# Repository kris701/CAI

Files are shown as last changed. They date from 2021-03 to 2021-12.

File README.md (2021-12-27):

banner
# Centralised Auxiliary Interface (CAI)

A project about centralizing a lot of the auxiliary systems for my 3D printer.
As well as add some new systems, like auto-screws, that makes the operation of the printer a lot easier!
It is also designed to be mounted on my [toolhead extension project](https://github.com/kris701/SnapMaker-Toolhead-Extensions).

### Auto-Screws
Automatic screws to take heatbed and toolhead off and on, to make it significantly easier to switch between CNC, Laser engraver and 3D-printer!

<p align="center">
  
  
</p>

### Menu System
Easy to modify menu system, with a rotary push button control.

menuWorks

### Auto-Setup
Single menu item, to setup all thats needed for CNC or 3D print.
Consisting of tightening screws, turning on LED and for 3D printing, turn on the nozzle blower.

autosetup

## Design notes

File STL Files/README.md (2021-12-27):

## Print Parts
### Interface Board
| InterfaceBoardModule_case | InterfaceBoardModule_Lid | InterfaceBoardModule_Knob |
|:---:|:---:|:---:|
| *Case* | *Lid* | *Knob* |

### LED Holder
| LEDHolder |
|:---:|
| *LED Holder* |

### Motor Controller Module
| MotorControllerModule_Case | MotorControllerModule_Lid |
|:---:|:---:|
| *Case* | *Lid* |

### Motherboard Module
| MotherboardModule_Case | MotherboardModule_Lid | MotherboardModule_Cover |
|:---:|:---:|:---:|
| *Case* | *Lid* | *Cover (Optional)* |

Note: The Cover should be printed in rubber filament.

### Screw Module
| ScrewModuleMk1_MainBody | ScrewModuleMk1_Lid |
|:---:|:---:|
| *Case* | *Lid* |

Note: These parts should be printed with very high infil, and in PETG if possible, since they will be exposed to a lot of heat and force.

### Backplate Extension
| SnapmakerBackplateExtension_Case | SnapmakerBackplateExtension_Lid | SnapmakerBackplateExtension_SideCap | SnapmakerBackplateExtension_TopCap |
|:---:|:---:|:---:|:---:|
| *Case* | *Lid* | *Side Cap (Optional)* | *Top Cap (Optional)* |

Note: The caps should be printed in rubber filament.

### Transistor Module Mk. 1
| TransistorModuleMk1_Case | TransistorModuleMk1_Lid |
|:---:|:---:|
| *Case* | *Lid* |

### Transistor Module Mk. 2
| TransistorModuleMk2_Case | TransistorModuleMk2_Lid |
|:---:|:---:|
| *Case* | *Lid* |

### Wire Holder (Optional)
| WireHolder |
|:---:|
| *Wire Holder (Optional)* |

The parts are put together with some M3 screws and bolts that i had. As well as being mounted to the printer with M4 screws.

## Printer settings

The config for a SnapMaker Original can be found under "Printing Config"

General config:

|Setting|Value|
|:---:|:---:|
| Layer Height |0.2mm |
| Top Thickness |0.8mm |
| Infil |35% |

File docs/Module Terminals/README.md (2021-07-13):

# Module Terminal Configuration
This is a little documentation on how i set up all the terminals on my setup.
It should however be noted, that you can set up the terminals however you want.

## Motherboard Module


The remaining ones for this module, is the interface board connector (7-pin) and the power connector (right next to it)

## Motor Controller Module
motorcontroller_b
motorcontroller_a

## Transistor Module
The transistor modules simply consist of a Type A input, and a Type D output.

## Screw Modules
Consist of just a Type D port.

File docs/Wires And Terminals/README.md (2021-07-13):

# Wires
Almost all cables in the project, consist of either 2 or 3 inner wires. (With the exception of the 7-pin cable for the front panel)
All the wires are made on a 1-1 basis, where each pin is connected to the same pin in the other end:



This makes it so that the same wires can be used for almost all ports (except if its a type D wire)

# Terminals
Pretty much all plugs is GX16-3-pin aviation plugs.
There are some different setups, for different terminals. But in general, they are intented to share some commonality.

All in all there are 3 different 3-proned terminals from the main controller:
## Type A
Type A is the basic variant, consisting of power and a single signal wire.

plugTypeA

## Type B
Type B is for motor controllers, where two are needed. One that has the GND plug, and one that has the +12v plug.

PlugTypeB

## Type C
Type C is for special future expansion, where the RX/TX pins can be used.

PlugTypeC

## Type D
There are also some wires and terminals, that only use two terminals (usually from a module to the thing being controlled, e.g. from a Transistor Module to LEDs)
They are esentially no different than the Base terminal, except there are no Signal:

PlugTypeD

(Note, that i removed the third pron from the connectors for all Type D terminals, so not to cause confusion)

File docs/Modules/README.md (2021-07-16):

# Overview of all modules

squareoverall

# Interface Module Mk. 1


# Transistor Module Mk. 1


# Transistor Module Mk. 2


# Back Extension Plates


# Motherboard Module Mk. 2


# Motor Controller Module Mk. 1


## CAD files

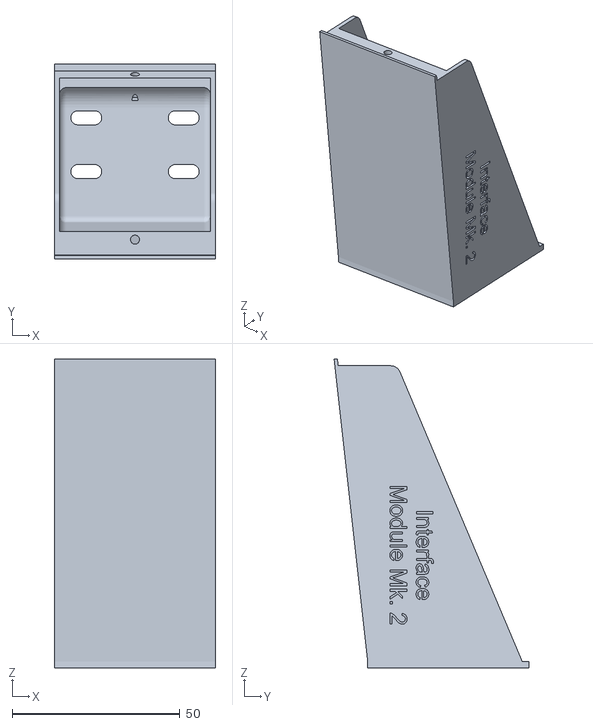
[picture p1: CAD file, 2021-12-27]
STL Files/Interfaceboard-Module-Case/InterfaceBoardModule_Case.stl
48.0 x 58.0 x 92.0

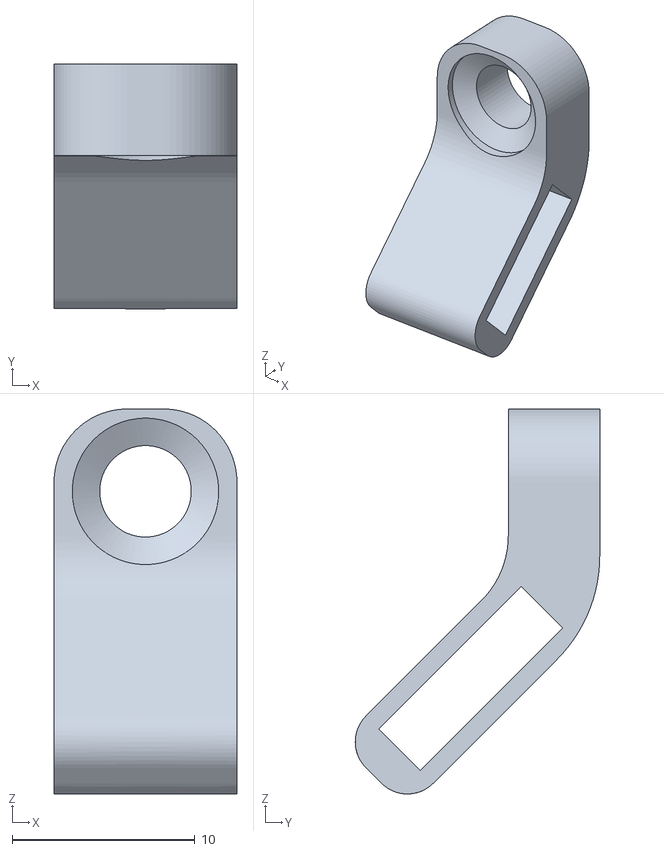
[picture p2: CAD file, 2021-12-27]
STL Files/LED-Holder/LEDHolder.stl
10.0 x 13.4 x 21.0

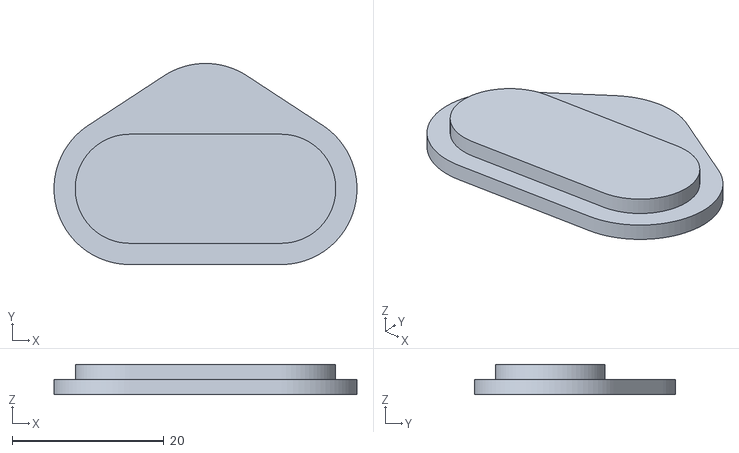
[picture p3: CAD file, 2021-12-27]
STL Files/Motherboard-Module-Case/MotherboardModule_Cover.stl
40.0 x 26.5 x 4.00

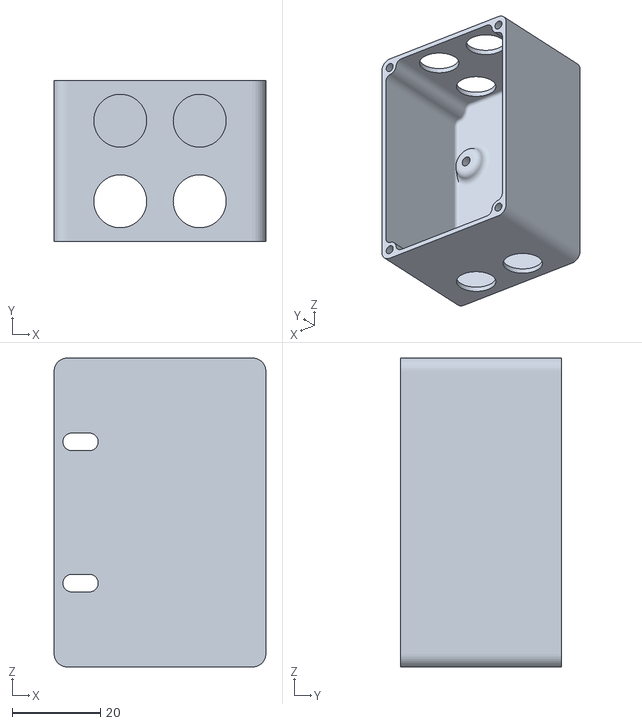
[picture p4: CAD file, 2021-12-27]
STL Files/Motor-Controller-Module-Case/MoterControllerModule_Case.stl
48.0 x 36.5 x 70.0

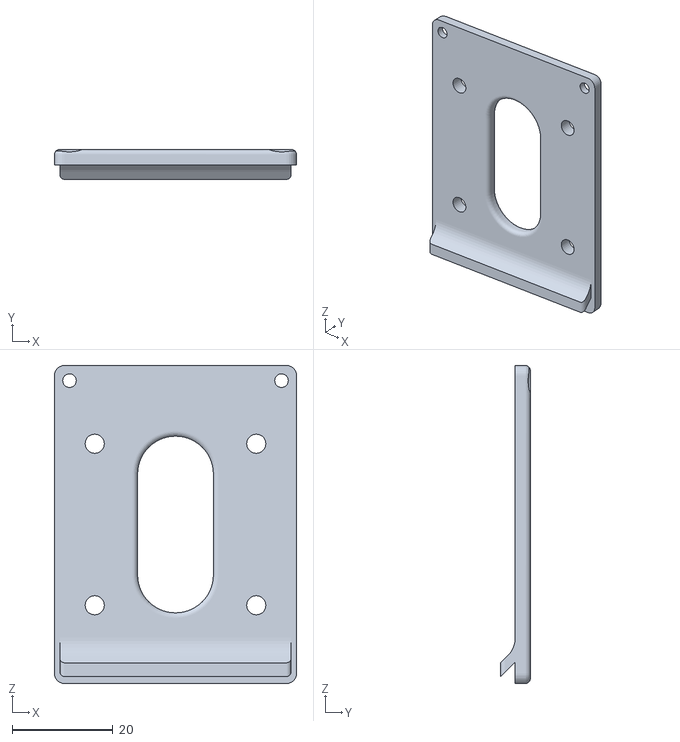
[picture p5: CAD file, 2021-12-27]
STL Files/Snapmaker-Backplate-Extension/SnapmakerBackplateExtension_Lid.stl
48.0 x 5.90 x 63.0

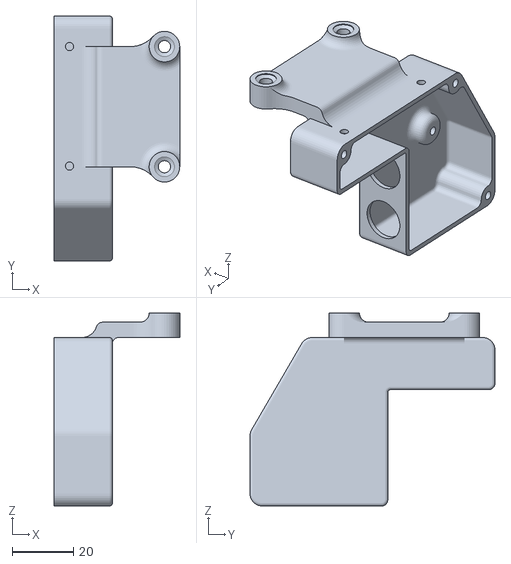
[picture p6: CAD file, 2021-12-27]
STL Files/Transistor-Module-Mk2/TransistorModuleMk2_Case.stl
41.0 x 80.0 x 63.0

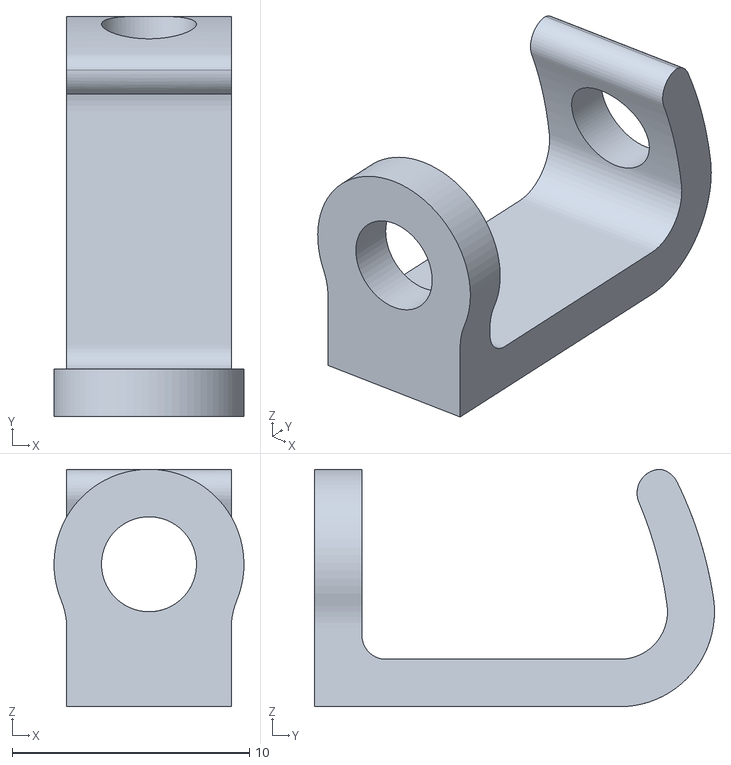
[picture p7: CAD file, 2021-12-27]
STL Files/Wire-Holder/WireHolder.stl
8.00 x 16.8 x 10.0

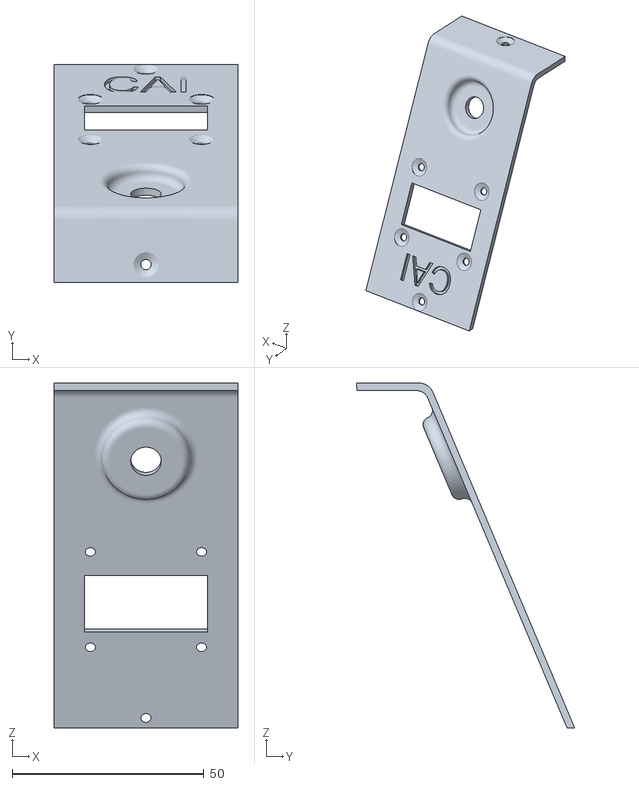
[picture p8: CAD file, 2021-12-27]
STL Files/Interfaceboard-Module-Case/InterfaceBoardModule_Lid.stl
48.0 x 57.0 x 90.0

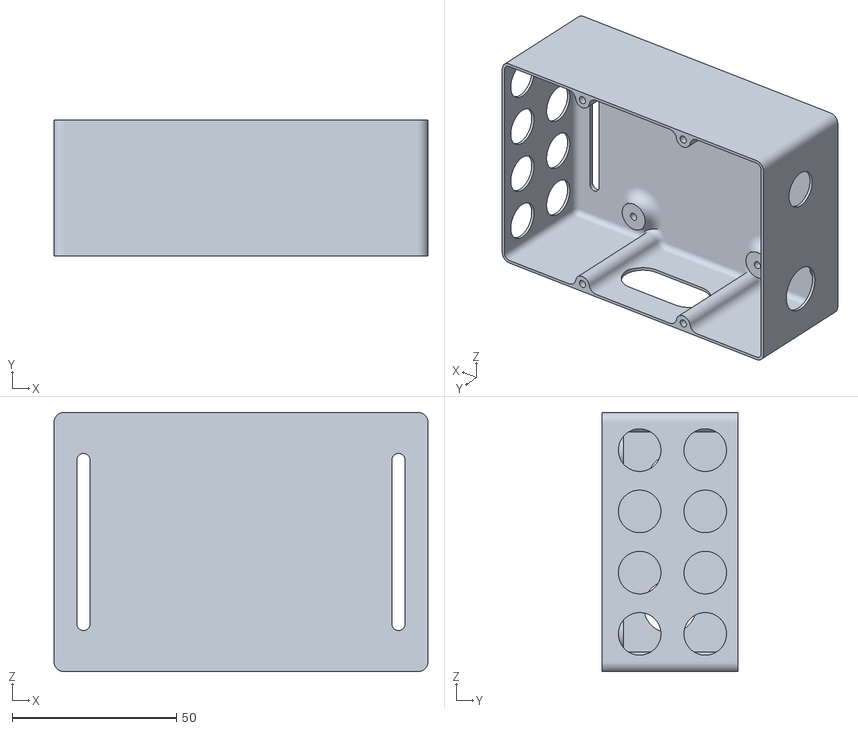
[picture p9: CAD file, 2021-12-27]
STL Files/Motherboard-Module-Case/MotherboardModule_Case.stl
114.0 x 41.5 x 79.0

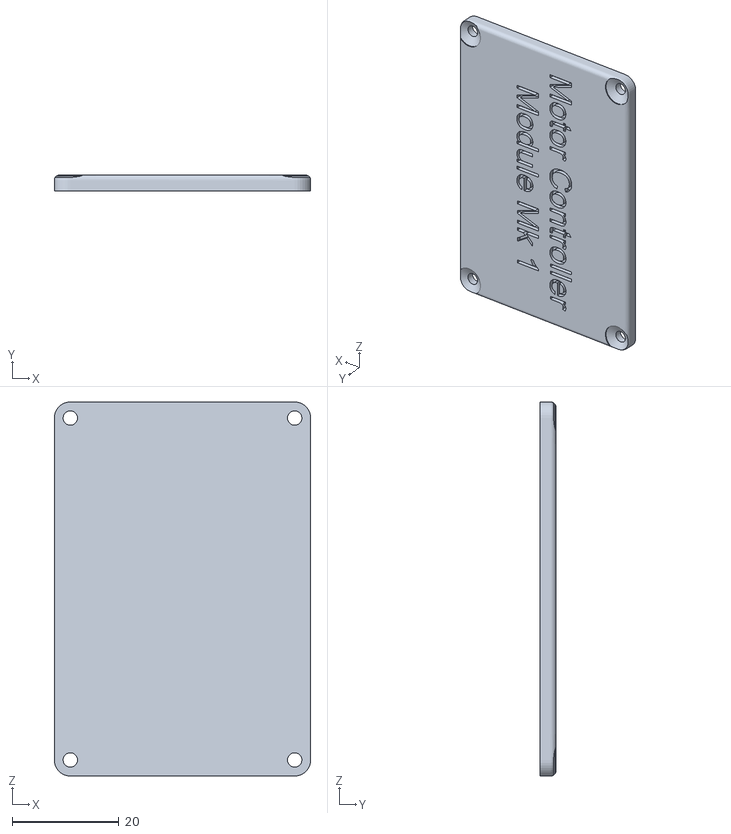
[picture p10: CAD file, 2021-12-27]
STL Files/Motor-Controller-Module-Case/MoterControllerModule_Lid.stl
48.0 x 3.00 x 70.0

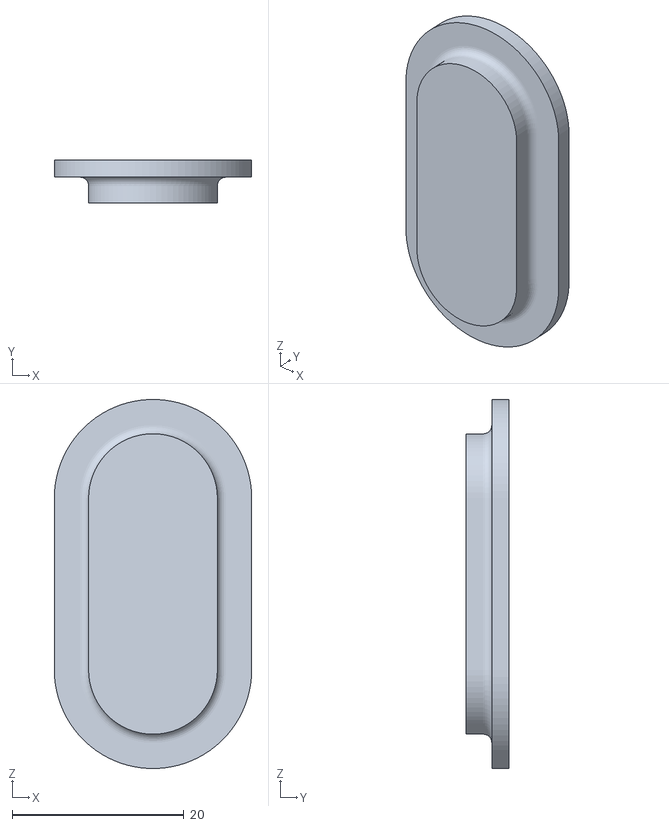
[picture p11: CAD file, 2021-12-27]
STL Files/Snapmaker-Backplate-Extension/SnapmakerBackplateExtension_TopCap.stl
23.0 x 5.00 x 43.0

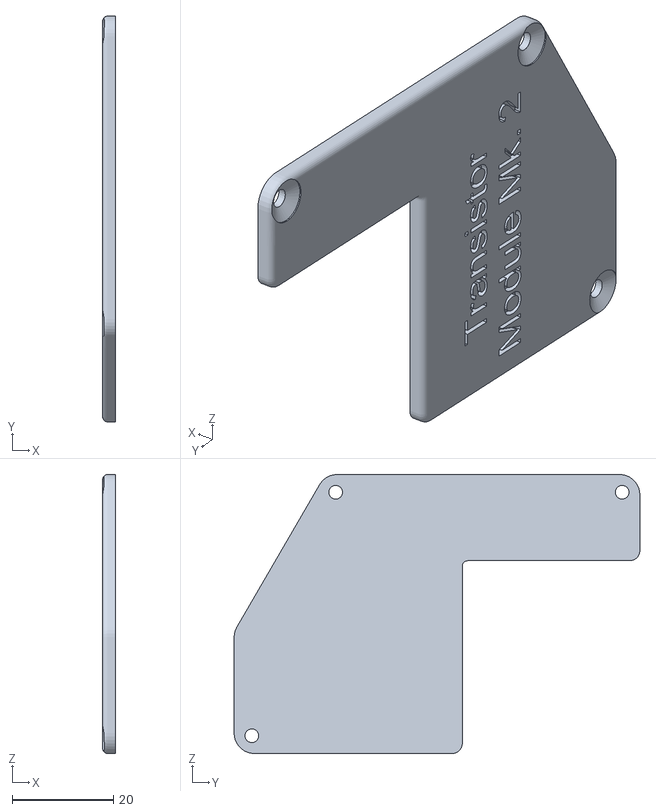
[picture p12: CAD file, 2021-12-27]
STL Files/Transistor-Module-Mk2/TransistorModuleMk2_Lid.stl
2.50 x 80.0 x 55.0

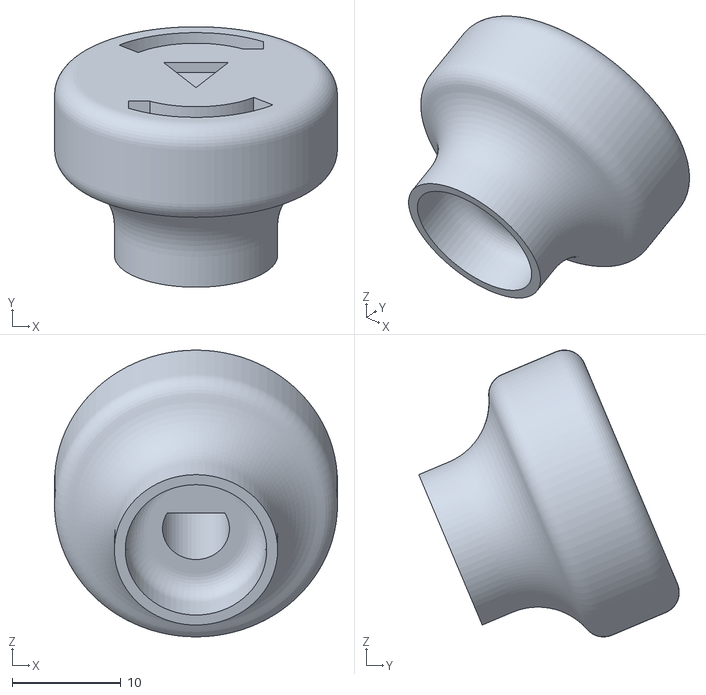
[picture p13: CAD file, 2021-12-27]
STL Files/Interfaceboard-Module-Case/InterfaceBoardModule_Knob.stl
26.0 x 23.9 x 26.3

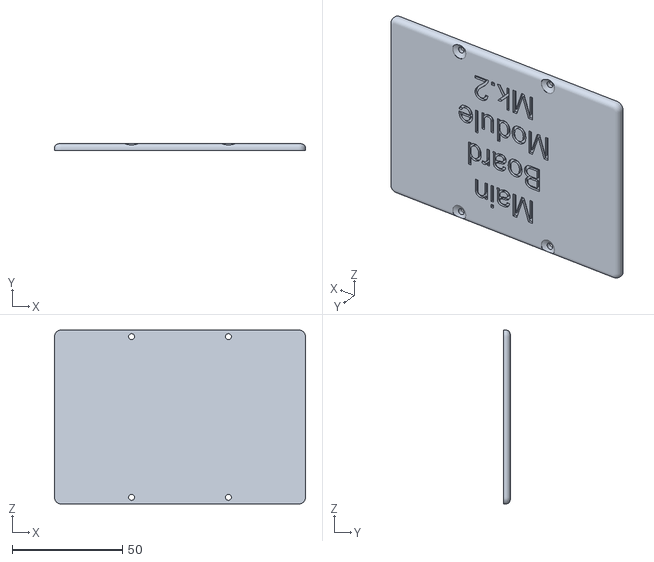
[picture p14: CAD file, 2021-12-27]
STL Files/Motherboard-Module-Case/MotherboardModule_Lid.stl
114.0 x 3.00 x 79.0

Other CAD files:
STL Files/Snapmaker-Backplate-Extension/SnapmakerBackplateExtension_Case.stl
STL Files/Snapmaker-Backplate-Extension/SnapmakerBackplateExtension_SideCap.stl
STL Files/Screw-Module-Mk1/ScrewModuleMk1_MainBody.stl
STL Files/Screw-Module-Mk1/ScrewModuleMk1_Lid.stl
3D Models/Interfaceboard-Module-Case/InterfaceBoardCaseMk2 v29.f3d
3D Models/LED-Holder/LED_Holder_Back v4.f3d
3D Models/Motherboard-Module-Case/MainBoardModuleCaseMk2 v26.f3d
3D Models/Motor-Controller-Module-Case/MotorControllerCase v6.f3d
3D Models/Screw-Module-Mk1/ScrewModule.f3d
3D Models/Snapmaker-Backplate-Extension/backextensionplate-Mk2 v25.f3d
3D Models/Transistor-Module-Mk1/TransisorModuleCase v19.f3d
3D Models/Transistor-Module-Mk2/TransisorModuleCaseMk2.f3d
3D Models/Wire-Holder/WireHolder v3.f3d
STL Files/Transistor-Module-Mk1/TransistorModuleMk1_Case.stl
STL Files/Transistor-Module-Mk1/TransistorModuleMk1_Lid.stl

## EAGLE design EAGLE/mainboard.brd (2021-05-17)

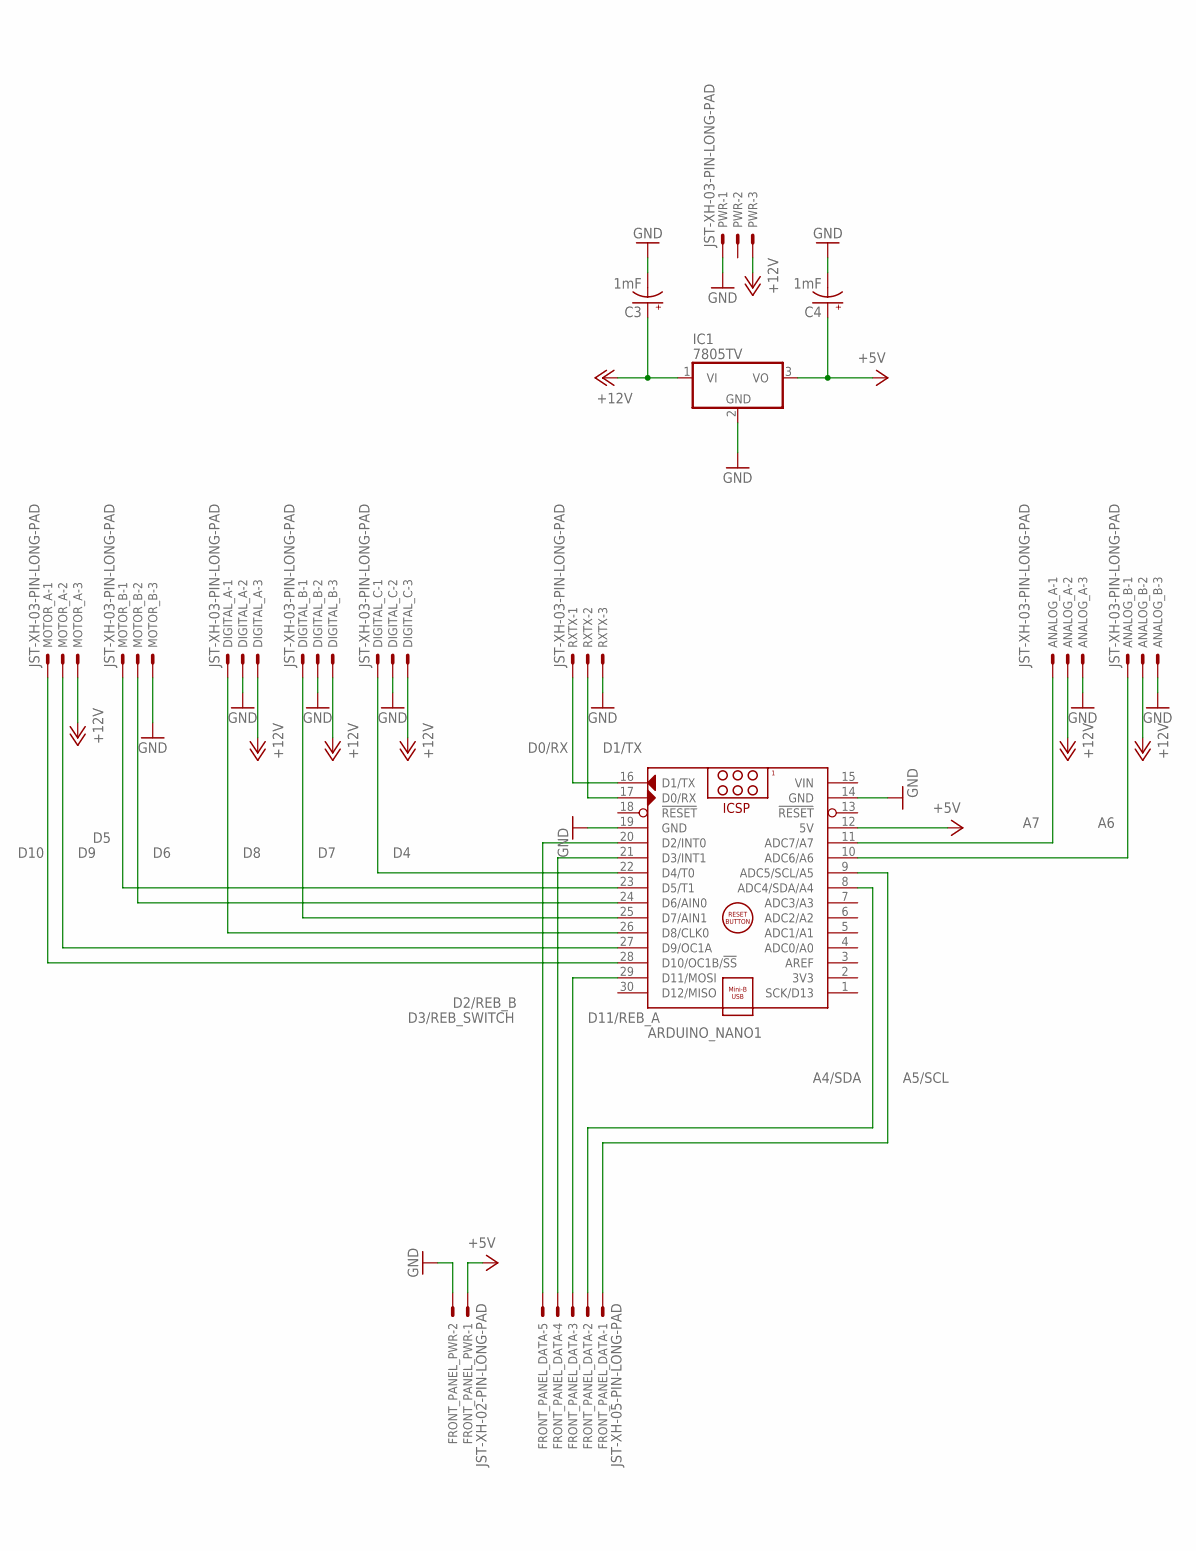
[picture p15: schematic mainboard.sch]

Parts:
ANALOG_A: JST-XH-03-PIN-LONG-PAD; JST-XH-03-PACKAGE-LONG-PAD
ANALOG_B: JST-XH-03-PIN-LONG-PAD; JST-XH-03-PACKAGE-LONG-PAD
ARDUINO_NANO1: ARDUINO_NANO
C3, C4: 1mF; CPOL-RADIAL-5MM-10MM
DIGITAL_A: JST-XH-03-PIN-LONG-PAD; JST-XH-03-PACKAGE-LONG-PAD
DIGITAL_B: JST-XH-03-PIN-LONG-PAD; JST-XH-03-PACKAGE-LONG-PAD
DIGITAL_C: JST-XH-03-PIN-LONG-PAD; JST-XH-03-PACKAGE-LONG-PAD
FRONT_PANEL_DATA: JST-XH-05-PIN-LONG-PAD; JST-XH-05-PACKAGE-LONG-PAD
FRONT_PANEL_PWR: JST-XH-02-PIN-LONG-PAD; JST-XH-02-PACKAGE-LONG-PAD
IC1: 7805TV; TO220V
MOTOR_A: JST-XH-03-PIN-LONG-PAD; JST-XH-03-PACKAGE-LONG-PAD
MOTOR_B: JST-XH-03-PIN-LONG-PAD; JST-XH-03-PACKAGE-LONG-PAD
PWR: JST-XH-03-PIN-LONG-PAD; JST-XH-03-PACKAGE-LONG-PAD
RXTX: JST-XH-03-PIN-LONG-PAD; JST-XH-03-PACKAGE-LONG-PAD

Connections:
+5V: ARDUINO_NANO1.12 (5V), C4.+, FRONT_PANEL_PWR.1, IC1.3 (VO)
+12V: ANALOG_A.2, ANALOG_B.2, C3.+, DIGITAL_A.3, DIGITAL_B.3, DIGITAL_C.3, IC1.1 (VI), MOTOR_A.3, PWR.3
A4/SDA: ARDUINO_NANO1.8 (ADC4/SDA/A4), FRONT_PANEL_DATA.2
A5/SCL: ARDUINO_NANO1.9 (ADC5/SCL/A5), FRONT_PANEL_DATA.1
A6: ANALOG_B.1, ARDUINO_NANO1.10 (ADC6/A6)
A7: ANALOG_A.1, ARDUINO_NANO1.11 (ADC7/A7)
D0/RX: ARDUINO_NANO1.17 (D0/RX), RXTX.2
D1/TX: ARDUINO_NANO1.16 (D1/TX), RXTX.1
D2/REB_B: ARDUINO_NANO1.20 (D2/INT0), FRONT_PANEL_DATA.5
D3/REB_SWITCH: ARDUINO_NANO1.21 (D3/INT1), FRONT_PANEL_DATA.4
D4: ARDUINO_NANO1.22 (D4/T0), DIGITAL_C.1
D5: ARDUINO_NANO1.23 (D5/T1), MOTOR_B.1
D6: ARDUINO_NANO1.24 (D6/AIN0), MOTOR_B.2
D7: ARDUINO_NANO1.25 (D7/AIN1), DIGITAL_B.1
D8: ARDUINO_NANO1.26 (D8/CLK0), DIGITAL_A.1
D9: ARDUINO_NANO1.27 (D9/OC1A), MOTOR_A.2
D10: ARDUINO_NANO1.28 (D10/OC1B/!SS), MOTOR_A.1
D11/REB_A: ARDUINO_NANO1.29 (D11/MOSI), FRONT_PANEL_DATA.3
GND: ANALOG_A.3, ANALOG_B.3, ARDUINO_NANO1.14 (GND), ARDUINO_NANO1.19 (GND), C3.-, C4.-, DIGITAL_A.2, DIGITAL_B.2, DIGITAL_C.2, FRONT_PANEL_PWR.2, IC1.2 (GND), MOTOR_B.3, PWR.1, RXTX.3
VIN: ARDUINO_NANO1.15 (VIN)

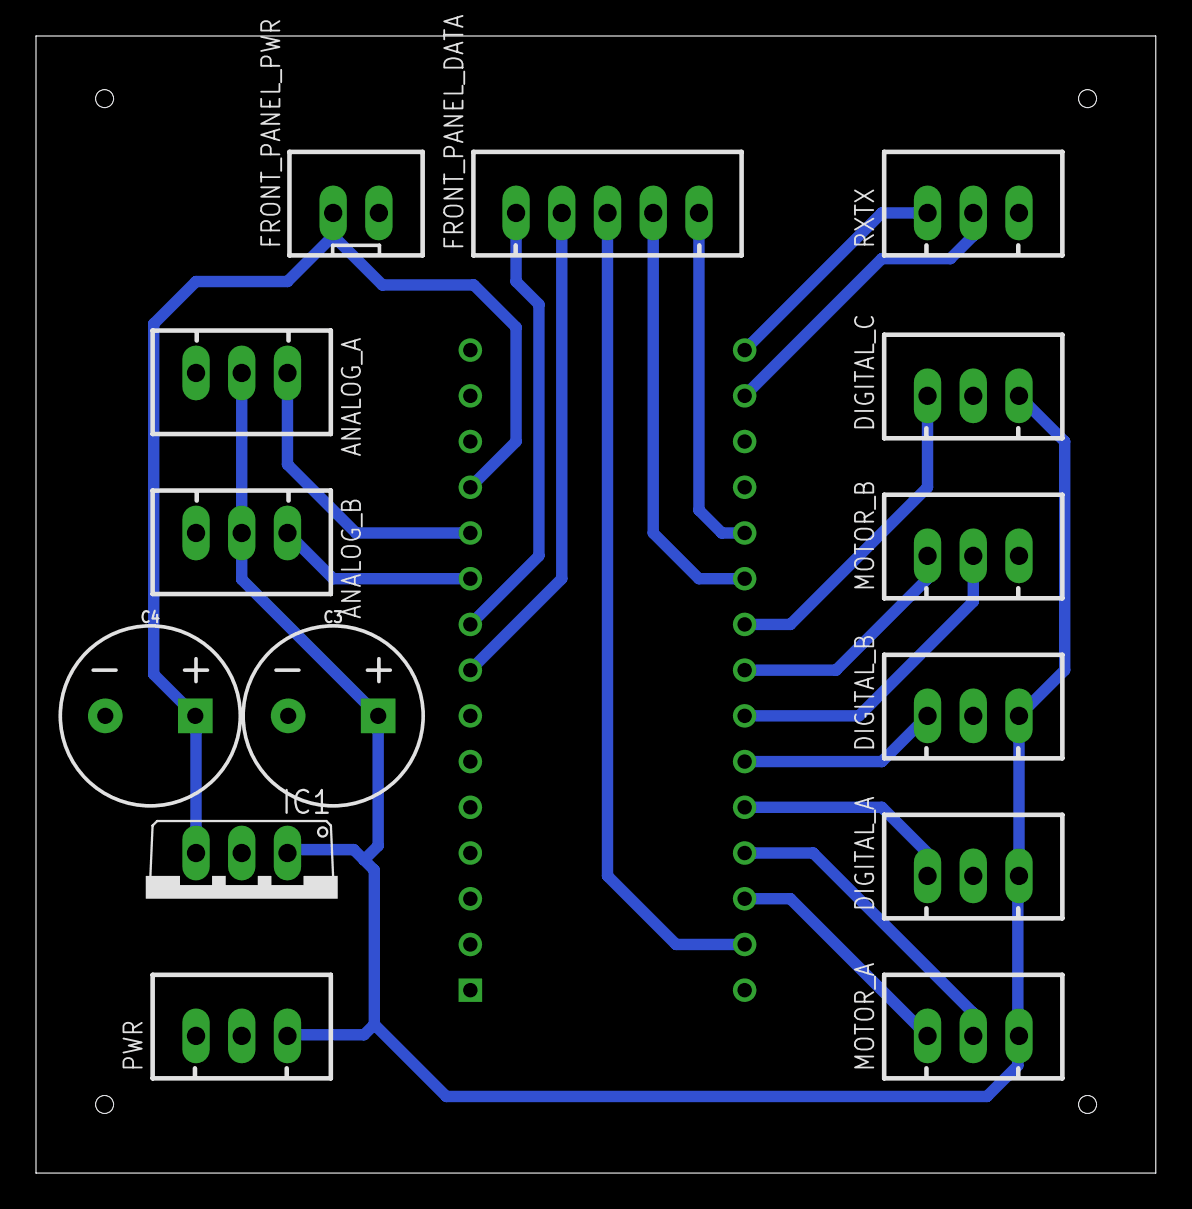
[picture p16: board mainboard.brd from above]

Board: 2 copper layers, 62.2 x 63.2 mm, 15 parts (1 on the bottom side), 19 nets.

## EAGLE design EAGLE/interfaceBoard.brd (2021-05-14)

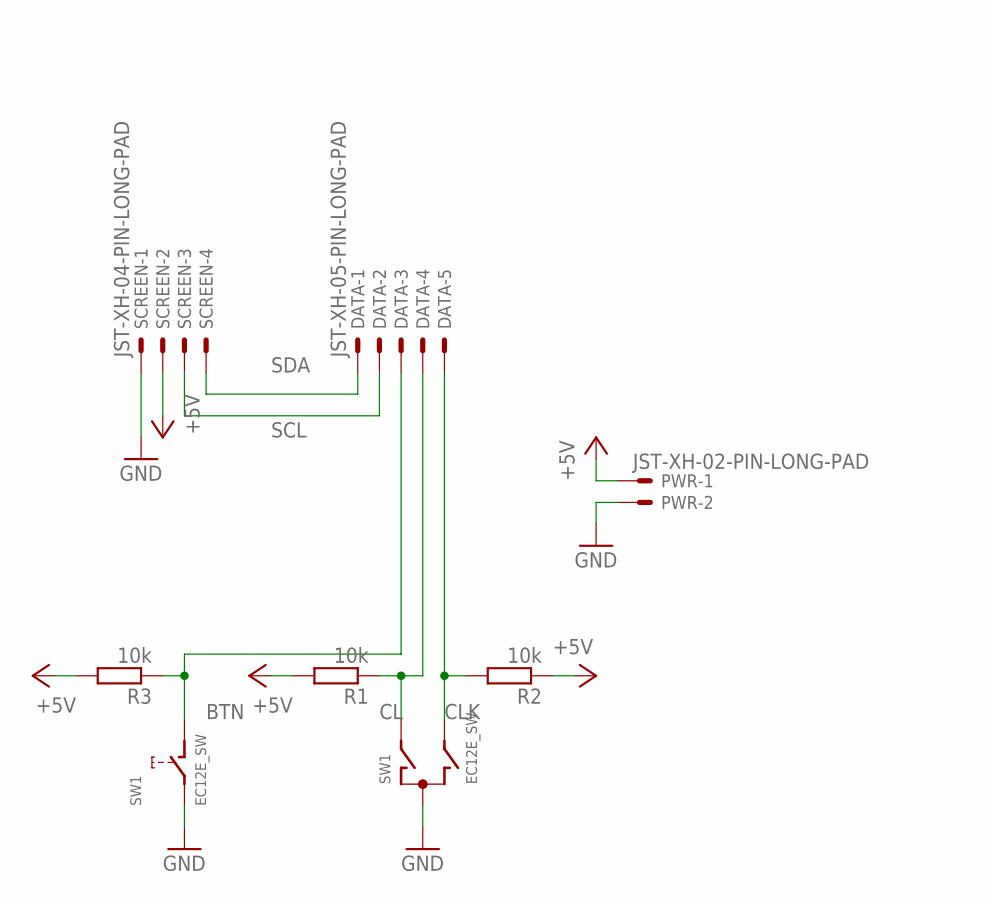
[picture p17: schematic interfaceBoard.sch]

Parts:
DATA: JST-XH-05-PIN-LONG-PAD; JST-XH-05-PACKAGE-LONG-PAD
PWR: JST-XH-02-PIN-LONG-PAD; JST-XH-02-PACKAGE-LONG-PAD
R1, R2, R3: 10k; 0204/7
SCREEN: JST-XH-04-PIN-LONG-PAD; JST-XH-04-PACKAGE-LONG-PAD
SW1: EC12E_SW; ALPS_EC12E_SW

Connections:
+5V: PWR.1, R1.2, R2.1, R3.2, SCREEN.2
BTN: DATA.3, R3.1, SW1.D (1)
CL: DATA.4, R1.1, SW1.A
CLK: DATA.5, R2.2, SW1.B
GND: PWR.2, SCREEN.1, SW1.C, SW1.E (2)
SCL: DATA.2, SCREEN.3
SDA: DATA.1, SCREEN.4

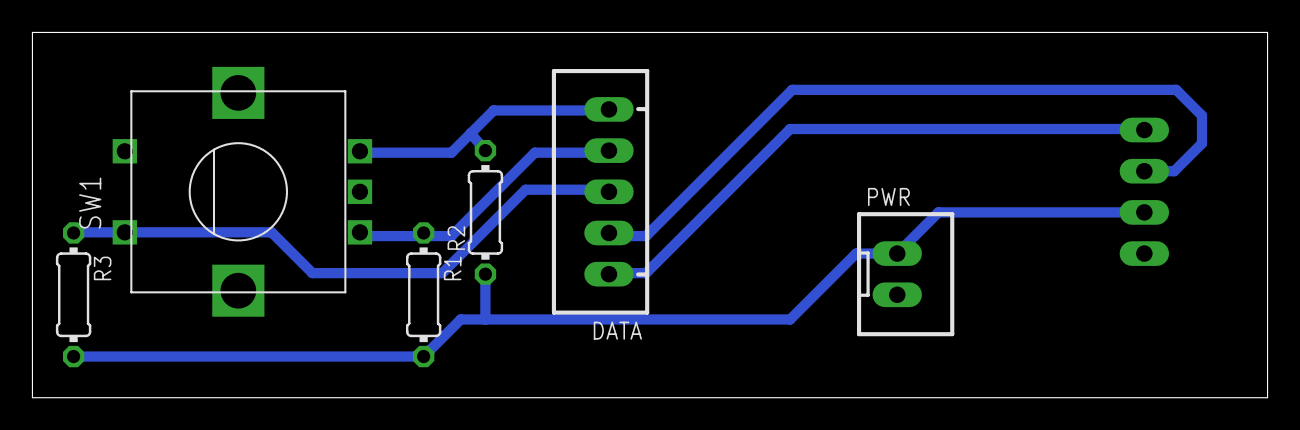
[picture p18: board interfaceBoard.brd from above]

Board: 2 copper layers, 76.2 x 22.5 mm, 7 parts (1 on the bottom side), 7 nets.

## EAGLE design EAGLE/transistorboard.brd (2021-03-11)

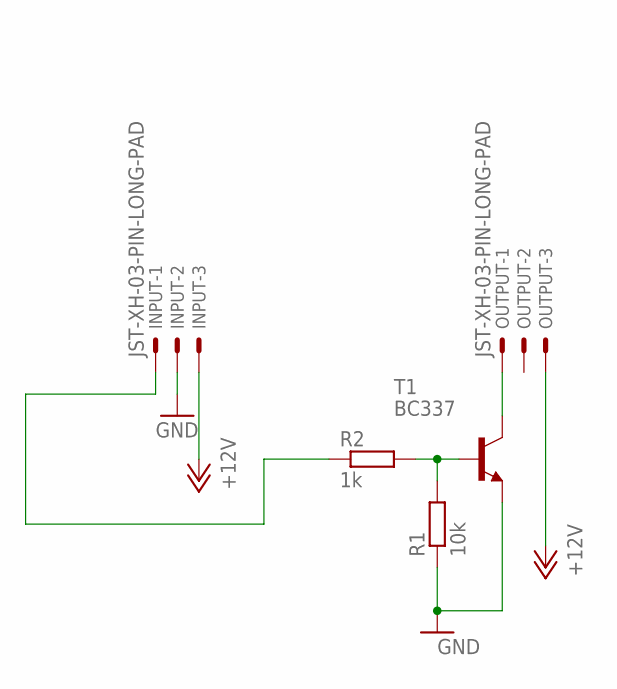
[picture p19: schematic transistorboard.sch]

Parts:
INPUT: JST-XH-03-PIN-LONG-PAD; JST-XH-03-PACKAGE-LONG-PAD
OUTPUT: JST-XH-03-PIN-LONG-PAD; JST-XH-03-PACKAGE-LONG-PAD
R1: 10k; 0204/7
R2: 1k; 0204/7
T1: BC337; TO92

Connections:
+12V: INPUT.3, OUTPUT.3
GND: INPUT.2, R1.1, T1.1 (E)
unnamed: OUTPUT.1, T1.3 (C)
unnamed: INPUT.1, R2.1
unnamed: R1.2, R2.2, T1.2 (B)

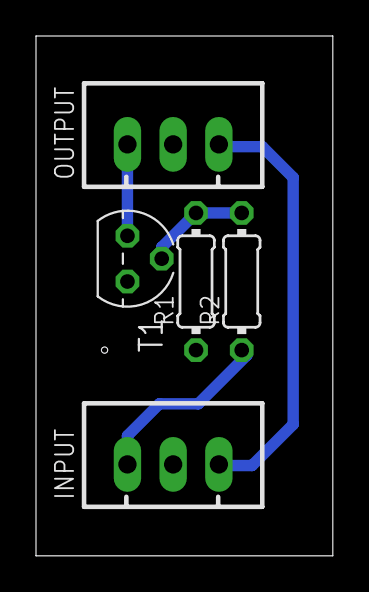
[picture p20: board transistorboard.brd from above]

Board: 2 copper layers, 16.5 x 28.9 mm, 5 parts (0 on the bottom side), 5 nets.

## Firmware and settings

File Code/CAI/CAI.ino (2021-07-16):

#include "CAI.h"
#include "ScreenDriver.h"
#include "RotaryButtonDriver.h"
#include "MenuController.h"
#include "Systems.h"

#pragma region Setup

ScreenDriver screenDriver = ScreenDriver();
RotaryButtonDriver rotaryButtonDriver(Interface_InrementRotationPin, Interface_DecrementRotationPin, Interface_EnterPin, IncrementFunc, DecrementFunc, EnterMenu);
MenuController menuController = MenuController();

uint8_t menuIndex = 1;
uint8_t currentMenuIndex = 0;

const MenuItem menuTree[MENU_TREE_SIZE] = USE_TREE;

#pragma endregion

#pragma region Base Methods

void setup()
{
#if SERIAL_PRINT
	Serial.flush();
	Serial.begin(115200);
	Serial.println(F("Warning: Serial print is on!"));
	Serial.println(F("Starting..."));
	delay(100);
#endif

	screenDriver.startDisplay();
	screenDriver.printIntro();
	screenDriver.printMenu(menuTree, MENU_TREE_SIZE, currentMenuIndex, menuIndex);
}

void loop() { 
	rotaryButtonDriver.Tick(); 
	delay(10); 
}

void IncrementFunc() {
	menuController.incrementMenuIndex(menuTree, MENU_TREE_SIZE, &currentMenuIndex, &menuIndex);
	screenDriver.printMenu(menuTree, MENU_TREE_SIZE, currentMenuIndex, menuIndex);
}

void DecrementFunc() {
	menuController.decrementMenuIndex(menuTree, MENU_TREE_SIZE, &currentMenuIndex, &menuIndex);
	screenDriver.printMenu(menuTree, MENU_TREE_SIZE, currentMenuIndex, menuIndex);
}

void EnterMenu() {
	screenDriver.printEnterMenu(menuTree, MENU_TREE_SIZE, currentMenuIndex, menuIndex);
	if (menuTree[menuIndex].command != NULL)
		screenDriver.printLoading();
	menuController.enterMenu(menuTree, MENU_TREE_SIZE, &currentMenuIndex, &menuIndex);
	screenDriver.printMenu(menuTree, MENU_TREE_SIZE, currentMenuIndex, menuIndex);
}

void backMethod() {
  int jumpCursor = 0;
  while (menuTree[jumpCursor].menuID != menuTree[menuIndex].parentID)
  {
    jumpCursor++;
    if (jumpCursor > MENU_TREE_SIZE)
      jumpCursor = 0;
  }
  
	while (menuTree[menuIndex].menuID != menuTree[currentMenuIndex].parentID)
  {
    menuIndex++;
    if (menuIndex > MENU_TREE_SIZE)
      menuIndex = 0;
  }
  currentMenuIndex = menuIndex;
  menuIndex = jumpCursor;
}

#pragma endregion

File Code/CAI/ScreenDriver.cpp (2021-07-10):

#include "ScreenDriver.h"

#ifndef _SCREENLIB
#define _SCREENLIB

// config for softwareI2Cmaster lib
#define I2C_HARDWARE 1
#define I2C_TIMEOUT 10
#define I2C_MAXWAIT 10
#define I2C_PULLUP 1
#define I2C_FASTMODE 1
#define SDA_PORT PORTC
#define SDA_PIN 4 // = A4
#define SCL_PORT PORTC
#define SCL_PIN 5 // = A5

// config for tinyprint lib
#define TP_PRINTLINES 0
#define TP_FLASHSTRINGHELPER 1
#define TP_NUMBERS 0
#define TP_FLOAT 0
#define TP_WINDOWSLINEENDS 0

#include <SH1106Lib.h>
#include "glcdfont.h"
#endif

static SH1106Lib display;

void ScreenDriver::startDisplay() {
	display.initialize();

	display.clearDisplay();

	display.setFont(font, fontWidth, fontHeight);
}

void ScreenDriver::printHeader() {
	display.clearDisplay();
	printRect(headerRect, WHITE);
	printText(F("CAI 1.0"), headerRect, 5,2, BLACK, TRANSPARENT);
}

void ScreenDriver::printMenu(const MenuItem menuTree[], const uint8_t treeSize, uint8_t currentMenuIndex, uint8_t menuIndex, bool isClick = false) {
	uint8_t printIndex = 0;
	uint8_t printMenuIndex = 0;
	uint8_t printMenuPage = 0;
	uint8_t printArrowIndex = 0;
	uint8_t printArrowPage = 0;
	uint8_t printArrowPageIndex = 0;

	bool keepBufferingPage = true;
	bool keepBuffering = true;

	for (uint8_t i = 0; i < treeSize; i++)
	{
		if (menuTree[i].parentID == menuTree[currentMenuIndex].menuID)
		{
			if ((printIndex % menuLength) == 0 && printIndex != 0)
			{
				if (!keepBufferingPage)
					keepBuffering = false;
				printMenuPage++;
				if (printArrowIndex == 0)
					printMenuIndex = i;
			}
			if (i == menuIndex)
			{
				keepBufferingPage = false;
				printArrowPageIndex = printIndex % menuLength;
				printArrowIndex = i;
				printArrowPage = printMenuPage;
			}

			if (keepBuffering)
				menuBuffer[(printIndex % menuLength)] = i;

			printIndex++;
		}
	}
	if (printIndex % menuLength != 0 && keepBuffering)
		for (uint8_t i = (printIndex % menuLength); i < menuLength; i++)
			menuBuffer[i] = UINT8_MAX;

	if (isClick)
	{
		hightlightMenuItem(currentMenuIndex, printArrowIndex, printArrowPageIndex);
	}
	else
	{
		printMenuHeader(menuTree, currentMenuIndex);
		printPageArrows(currentMenuIndex, printArrowPage, printMenuPage);
		printMenuItems(menuTree, currentMenuIndex, printArrowPage, printMenuIndex, printArrowIndex);
		printCursor(currentMenuIndex, printArrowIndex, printArrowPageIndex);
		lastMenuIndex = currentMenuIndex;
	}
}

void ScreenDriver::printMenuHeader(const MenuItem menuTree[], uint8_t currentMenuIndex) {
	if (lastMenuIndex != currentMenuIndex)
	{
		printRect(menuHeaderRect, BLACK);
		printTextln(menuTree[currentMenuIndex].name, menuHeaderRect, 10, 2);
	}
}

void ScreenDriver::printPageArrows(uint8_t currentMenuIndex, uint8_t printArrowPage, uint8_t printMenuPage) {
	if (lastMenu != printArrowPage || lastMenuIndex != currentMenuIndex)
	{
		printRect(pageArrowRect, BLACK);
		if (printMenuPage > printArrowPage)
			printText(F("v"), pageArrowRect, 0, 40);
		if (printArrowPage > 0)
			printText(F("^"), pageArrowRect, 0, 5);
	}
}

void ScreenDriver::printMenuItems(const MenuItem menuTree[], uint8_t currentMenuIndex, uint8_t printArrowPage, uint8_t printMenuIndex, uint8_t printArrowIndex) {
	if (lastMenu != printArrowPage || lastMenuIndex != currentMenuIndex)
	{
		printRect(menuItemsRect, BLACK);
		for (uint8_t i = 0; i < menuLength; i++)
		{
			if (menuBuffer[i] != UINT8_MAX)
				printTextln(menuTree[menuBuffer[i]].name, menuItemsRect);
		}
		lastMenu = printArrowPage;
	}
}

void ScreenDriver::hightlightMenuItem(uint8_t currentMenuIndex, uint8_t printArrowIndex, uint8_t printArrowPageIndex) {
	if (lastCursorIndex != printArrowIndex || lastMenuIndex != currentMenuIndex)
	{
		Rectangle coverText = { menuItemsRect.x, menuItemsRect.y + fontHeight * printArrowPageIndex, menuItemsRect.width, fontHeight };
		printRect(coverText, WHITE);

		lastCursorIndex = printArrowIndex;
	}
}

void ScreenDriver::printCursor(uint8_t currentMenuIndex, uint8_t printArrowIndex, uint8_t printArrowPageIndex) {
	if (lastCursorIndex != printArrowIndex || lastMenuIndex != currentMenuIndex)
	{
		printRect(cursorRect, BLACK);

		printTextln(F("=>"), cursorRect, 5, printArrowPageIndex * fontHeight);

		lastCursorIndex = printArrowIndex;
	}
}

void ScreenDriver::printText(const __FlashStringHelper* text, Rectangle drawRect, uint8_t xOffset = 0, uint8_t yOffset = 0, uint8_t frontColor = WHITE, uint8_t backColor = BLACK)
{
	if (drawRect.x != lastRect.x || 
		drawRect.y != lastRect.y || 
		drawRect.width != lastRect.width || 
		drawRect.height != lastRect.height)
	{
		setTextSettings(drawRect.x + xOffset, drawRect.y + yOffset, frontColor, backColor);
		lastRect = drawRect;
	}
	else
	{
		if (xOffset != 0 || yOffset != 0)
			setTextSettings(drawRect.x + xOffset, drawRect.y + yOffset, frontColor, backColor);
	}
	display.print(text);
}

void ScreenDriver::printTextln(const __FlashStringHelper* text, Rectangle drawRect, uint8_t xOffset = 0, uint8_t yOffset = 0, uint8_t frontColor = WHITE, uint8_t backColor = BLACK)
{
	printText(text, drawRect, xOffset, yOffset, frontColor, backColor);
	setVCursor(drawRect.x, currentY + fontHeight);
}

void ScreenDriver::setTextSettings(uint8_t x, uint8_t y, uint8_t frontColor, uint8_t backColor)
{
	display.setTextColor(frontColor, backColor);
	setVCursor(x, y);
}

void ScreenDriver::printIntro() {
	printText(F("CAI Starting..."), menuItemsRect, 0, 10);
	delay(2000);
	display.clearDisplay();
	printHeader();
}

void ScreenDriver::printLoading() {
	printRect(menuItemsRect, BLACK);
	printRect(pageArrowRect, BLACK);
	printRect(cursorRect, BLACK);
	printText(F("Processing..."), menuItemsRect, 0, 10);
}

void ScreenDriver::setVCursor(uint8_t x = 0, uint8_t y = 0) {
	currentX = x;
	currentY = y;
	display.setCursor(x, y);
}

void ScreenDriver::printRect(Rectangle rect, uint8_t color) {
	display.fillRect(rect.x, rect.y, rect.width, rect.height, color);
}

void ScreenDriver::printEnterMenu(const MenuItem menuTree[], const uint8_t treeSize, uint8_t currentMenuIndex, uint8_t menuIndex) {
	lastMenuIndex = -1;
	printMenu(menuTree, treeSize, currentMenuIndex, menuIndex, true);
	delay(50);
}

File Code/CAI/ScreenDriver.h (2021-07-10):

// ScreenDriver.h

#ifndef _SCREENDRIVER_h
#define _SCREENDRIVER_h

#ifndef _CLASSES_h
	#include "Classes.h"
#endif

#ifndef _CAI_h
	#include "CAI.h"
#endif

struct Rectangle {
	uint8_t x;
	uint8_t y;
	uint8_t width;
	uint8_t height;
};

const uint8_t screenWidth = 128;
const uint8_t screenHeight = 64;
const uint8_t fontHeight = 8;
const uint8_t fontWidth = 5;
static const uint8_t menuLength = 5;
const Rectangle headerRect = { 0, 0, 127, 11 };
const Rectangle cursorRect = { 0, 22, 19, 41 };
const Rectangle menuHeaderRect = { 20, 12, 97, 9 };
const Rectangle menuItemsRect = { 20, 22, 97, 41 };
const Rectangle pageArrowRect = { 118, 12, 9, 51 };

class ScreenDriver {
private:
	uint8_t currentX = 0;
	uint8_t currentY = 0;

	uint8_t lastMenu = 0;
	uint8_t lastCursorIndex = 0;
	uint8_t lastMenuIndex = -1;
	Rectangle lastRect = {};
	uint8_t menuBuffer[menuLength];

	void ScreenDriver::setVCursor(uint8_t x = 0, uint8_t y = 0);
	void ScreenDriver::printRect(Rectangle rect, uint8_t color);

	void ScreenDriver::printText(const __FlashStringHelper* text, Rectangle drawRect, uint8_t xOffset = 0, uint8_t yOffset = 0, uint8_t frontColor = 1, uint8_t backColor = 0);
	void ScreenDriver::printTextln(const __FlashStringHelper* text, Rectangle drawRect, uint8_t xOffset = 0, uint8_t yOffset = 0, uint8_t frontColor = 1, uint8_t backColor = 0);

	void ScreenDriver::printHeader();
	void ScreenDriver::printMenuHeader(const MenuItem menuTree[], uint8_t currentMenuIndex);
	void ScreenDriver::printMenuItems(const MenuItem menuTree[], uint8_t currentMenuIndex, uint8_t printArrowPage, uint8_t printMenuIndex, uint8_t printArrowIndex);
	void ScreenDriver::hightlightMenuItem(uint8_t currentMenuIndex, uint8_t printArrowIndex, uint8_t printArrowPageIndex);
	void ScreenDriver::printCursor(uint8_t currentMenuIndex, uint8_t printArrowIndex, uint8_t printArrowPageIndex);
	void ScreenDriver::printPageArrows(uint8_t currentMenuIndex, uint8_t printArrowPage, uint8_t printMenuPage);

	void ScreenDriver::setTextSettings(uint8_t x, uint8_t y, uint8_t frontColor = 1, uint8_t backColor = 0);
	
public:
	ScreenDriver(){};

	void ScreenDriver::startDisplay();
	void ScreenDriver::printMenu(const MenuItem menuTree[], const uint8_t treeSize, uint8_t currentMenuIndex, uint8_t menuIndex, bool isClick = false);
	void ScreenDriver::printEnterMenu(const MenuItem menuTree[], const uint8_t treeSize, uint8_t currentMenuIndex, uint8_t menuIndex);
	void ScreenDriver::printIntro();
	void ScreenDriver::printLoading();
};

#endif

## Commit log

2021-03-05 * got a basic menu structure to work
    [Configuration.h]
2021-03-05 * Cleaned up * Added the systems needed to display text on the OLED screen * Added IO drivers for future modules
2021-03-05 * Removed unused files * Optimised some data types * Made a macro, to switch serial on and off
    [Configuration.h]
2021-03-05 * Added the board schematics for the PCB boards
    [mainboard.brd, mainboard.sch, transistorboard.brd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]
2021-03-06 * Fixed issue #1 * Also added some more serial debugging
    [CAI.ino, ModuleDrivers.cpp, ScreenDriver.h]
2021-03-08 * Added a delay in loop, so not to waste too much power
    [CAI.ino]
2021-03-10 * Changed the rotary encoder code, to match that of the following source: - https://www.instructables.com/Tutorial-of-Rotary-Encoder-With-Arduino/ * Changed boards and schematic, so that interrupt pi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
    [mainboard.brd, mainboard.sch]
2021-03-10 * Changed symbolic constants to fit mother board * Removed function pointers from the `RotaryButtonDriver` class, since they are not used * Added pinModes for all pins used for the Rotary Button
2021-03-10 * Made some minor changes on the motherboard, so that the +5v rail is connected to +5v on the arduino instead of vin
    [mainboard.brd, mainboard.sch]
2021-03-10 * Optimised the motherboard a little
    [mainboard.brd, mainboard.sch]
2021-03-11 * Moved all EAGLE files into the project * Removed old copy-pasted boards * Updated .gitignore
    [mainboard.brd, mainboard.sch, transistorboard.brd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]
2021-03-11 * Made some more work with properties * Made two classes in ModuleDrivers instead of just one * Fixed an issue, where the "SET" methods of properties didnt work * Made some initial checking on valid 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
    [CAI.ino, ModuleDrivers.cpp, ScreenDriver.h]
2021-03-12 * Made some value checking * Also added a flag `SERIAL_DEBUG` to print errors that arrise from `Set` methods
    [CAI.h, CAI.ino, ScreenDriver.cpp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]
2021-03-12 * Cleaned up and fixed the macro `CHECKVALUE`
    [ScreenDriver.h]
2021-03-16 * Fixed code so it works with the SH1106 chip * Made initial menu work * Removed serial on warning * Now uses significantly less memory from new library
    [CAI.h, CAI.ino, ScreenDriver.cpp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]
2021-03-17 * Made the entire screen refreshing sequence a lot more smooth * Added some more structured rectangle controls, to make it easier to allign items * Made a highlight animation when a button is clicked
2021-03-17 * Took care of issue #2 - Configuration of different systems have been put in a seperate file and header
    [CAI.h, CAI.ino, ScreenDriver.cpp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]
2021-05-05 * Added all the current 3D design files (Fusion files) * Added the Mk. 2 version of the transistor board, that mounts on the toolhead
    [MainBoardModuleCase v17.f3d, Module.f3d, MotorControllerCase v6.f3d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]
2021-05-08 * Added a LED holder for a little LED strip * Updated the transistor module mk II * Updated the back extension plate to mk. II
    [LED_Holder_Back v4.f3d, Module.f3d, backextensionplate v21.f3d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]
2021-05-11 * Got the rotatry encoder, so now the code works with it
2021-05-12 * Removed the need for interrupts, uses a Tick logic instead
2021-05-13 * Designed an interface board
    [interfaceBoard.brd, interfaceBoard.sch]
2021-05-14 * Small fix where the +5v and GND rail was reversed to the LCD screen on the interface board
    [interfaceBoard.brd, interfaceBoard.sch]
2021-05-17 * Fixed a small bug in the dual module driver * Updated the mainboard
    [mainboard.brd]
2021-06-17 * Added new Interface module case fusion files
    [InterfaceBoardCaseMk2 v23.f3d]
2021-07-10 * Made the menu correct, with all the items thats actually on the machine
    [CAI.h, CAI.ino, ScreenDriver.cpp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]
2021-07-10 * Added a missing `pinMode()` to the `ModuleDriver` constructor * Updates the transistor module mk 2 model * Added a new screw module * Updated the main board case to a Mk. 2 variant
    [MainBoardModuleCase v17.f3d, MainBoardModuleCaseMk2 v26.f3d, Module.f3d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]
2021-07-10 * Small change in the transistor module Mk. 2, so that they can be "stacked" in series if needed
    [Module.f3d]
2021-07-12 * Fixed the rotation direction of the screw code * Removed the `turnFANON()` call from the `basecnc()` function * Updated the front panel, to include the name of the project, and a nob to turn with
    [InterfaceBoardCaseMk2 v23.f3d]
2021-07-13 * Updated the interface board, to include the module name on the side * Also made the knob a little lower profile
    [InterfaceBoardCaseMk2 v23.f3d, InterfaceBoardCaseMk2 v29.f3d]
2021-07-13 * Updated the knob for the interface board again * Added a wire holder, for cable management * Increased the screw/unscrew time for the screw modules, and made it as a variable that can be changed
    [InterfaceBoardCaseMk2 v29.f3d, WireHolder v3.f3d]
2021-07-16 * Added a "hold" option for dual motor drivers, so that to make sure that they stay in place under a print
2021-12-27 * Added print settings * Added STL files * Removed old design files
    [InterfaceBoardModule_Case.stl, InterfaceBoardModule_Knob.stl, InterfaceBoardModule_Lid.stl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]

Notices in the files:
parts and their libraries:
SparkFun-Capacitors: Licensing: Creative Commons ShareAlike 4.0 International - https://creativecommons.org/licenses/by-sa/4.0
